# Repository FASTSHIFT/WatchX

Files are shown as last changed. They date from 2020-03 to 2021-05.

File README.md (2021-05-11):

# WatchX
> 开源智能手表, 高质量流畅(60FPS+)的动画效果, 易于扩展的系统框架.

演示视频：https://www.bilibili.com/video/BV1AK4y1b7Xd

## UI框架
> [LittlevGL V6.1.2](https://github.com/lvgl/lvgl/releases/tag/v6.1.2)

## 硬件配置
* 1.主控: STM32F411CEU6 (主频:100MHz RAM:128KB ROM:512KB)
* 2.屏幕: ST7789 IPS 1.14inch SPI接口 135x240分辨率 100Hz刷新率
* 3.输入设备: 按键x3
* 4.RTC:MCU内置RTC时钟
* 5.加速度计:MPU6050
* 6.气压计:BMP180
* 7.电源管理:TP4056 + TPS63070
## 功能
* 1.时间显示
* 2.温度显示
* 3.气压显示
* 4.海拔显示
* 5.秒表
* 6.亮度控制
* 7.时间设置
* 8.[Arduboy](https://github.com/Arduboy/Arduboy)/[Arduboy2](https://github.com/MLXXXp/Arduboy2) Game System
* 9.自动关机(5-300sec)
* 10.待续...

## 成品展示
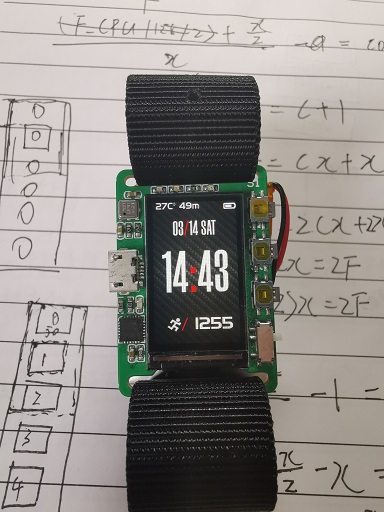
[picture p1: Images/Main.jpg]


 [更多>>](https://github.com/FASTSHIFT/WatchX/blob/master/Images)

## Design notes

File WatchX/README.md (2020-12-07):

# WatchX 更新日志
> https://github.com/FASTSHIFT/WatchX

## [v0.1] - 2020-03-07
* 1.框架搭建完成，UI基于littlevGL v6.1.2
* 2.优化屏幕驱动，刷新率提升至104FPS

## [v0.2] - 2020-03-11
* 1.主表盘界面完成
* 2.设置界面完成
* 3.时间设置界面完成

## [v0.3] - 2020-03-12
* 1.秒表完成
* 2.海拔表完成
* 3.About完成
* 4.所有功能基本完工

## [v0.4] - 2020-03-14
* 1.添加LV_OBJ_ADD_ANIM，更简洁的动画绑定

## [v0.5] - 2020-03-18
* 1.添加低功耗模式
* 2.添加Arduboy Game System
* 3.添加游戏 "CHRI-BOCCHI CAT"

## [v0.6] - 2020-03-23
* 1.海拔显示添加自动量程
* 2.添加MillisTaskManager，可统计CPU占用率
* 3.添加时间上下滑动特效

## [v0.7] - 2020-05-03
* 1.屏幕使用DMA发送，配合lvgl乒乓缓冲，画面无撕裂
* 2.Brightness更改为Backlight

## [v0.8] - 2020-06-27
* 1.修复电量显示的问题
* 2.添加 电源使能保持脚POWER_ON 和 电源使能按键状态读取脚POWER_EN
* 3.添加屏幕亮度掉电保存支持
* 4.添加自动待机时间设置以及掉电保存支持
* 5.感谢"日天电子工作室"提出的改进建议
* 6.修改了一些函数的命名

## [v0.9] - 2020-07-30
* 1.更新MillisTaskManager库，无需手动指定ID
* 2.TFT_LED_Pin 更名为 TFT_BLK_Pin
* 3.添加部分注释
* 4.Home更名为DialPlate(表盘)页面，Settings更名为MainMenu页面
* 5.更新PageManager v1.4
* 6.添加Arduboy2

## [v1.0] - 2020-12-07
* 1.POWER初始化整合
* 2.修改默认的动画曲线，更强的非线性效果，lv_anim_path_ease_in_out -> lv_anim_path_ease_out
* 3.修正错误的单词拼写，xxx_Creat -> xxx_Create， Fouce -> Focus
* 4.加大lv_disp_buf，使用两个半屏buffer，提升刷新率
* 5.去除FileGroup.h
* 6.更新海拔显示的tick自适应方法

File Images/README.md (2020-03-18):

# 成品展示
> 1.主页面



> 2.功能页面

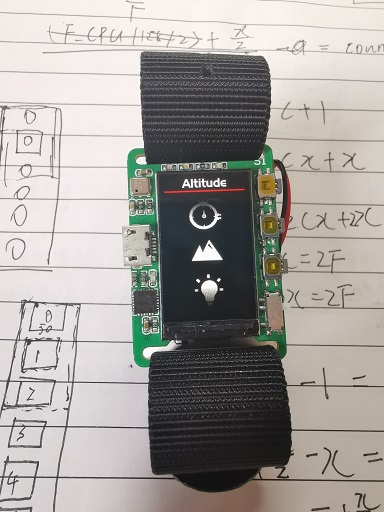
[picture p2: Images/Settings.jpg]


> 3.秒表

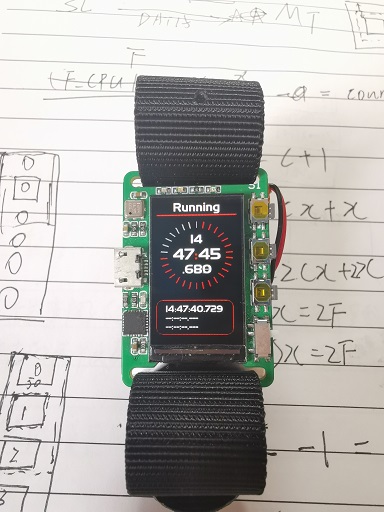
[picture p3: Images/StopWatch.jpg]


> 4.高度

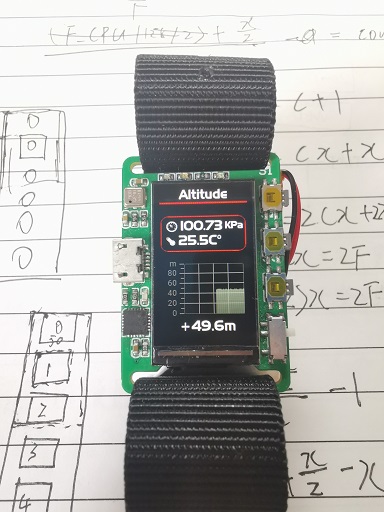
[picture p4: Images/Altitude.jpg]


> 5.亮度

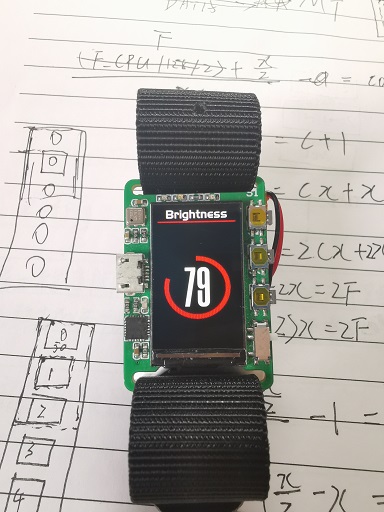
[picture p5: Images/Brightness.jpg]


> 6.时间设置

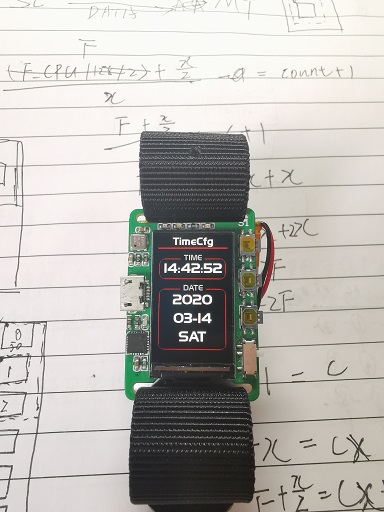
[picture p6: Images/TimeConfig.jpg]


> 7.关于

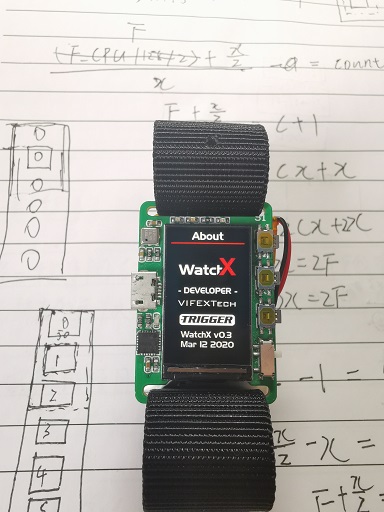
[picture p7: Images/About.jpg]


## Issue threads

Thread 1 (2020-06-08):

Compile error

yingjiexiong, 2020-06-08:
i had downloaded this project and  watching you video , it's so cool , but when I  ready to compile this project I find something error that located in audio.app 160 line, 164 line 170 line 175line .those error are same they are #19:extra text after expected end of number .

FASTSHIFT, 2020-06-10:
@yingjiexiong
I used Keil MDK-ARM v5.25 to compile, what compiler are you using?

yingjiexiong, 2020-06-15:
> @yingjiexiong
> I used Keil MDK-ARM v5.25 to compile, what compiler are you using?

thanks for your reply, I am using v5.14. I need to upgrade my compiler?

FASTSHIFT, 2020-06-15:
@yingjiexiong
Yes

tanhailong, 2020-09-04:
楼主我使用你这个代码编译不通过，我使用的MDK版本是V5.14,还是在编译这个工程的时候需要在mdk里面设置一下呢，期待你的回复

FASTSHIFT, 2020-09-04:
@tanhailong 请使用MDK-ARM v5.25以上的版本进行编译

heimareed, 2020-09-04:
> @tanhailong 请使用MDK-ARM v5.25以上的版本进行编译

楼主真快，还在回复，你就上去了~

tanhailong, 2020-09-04:
> @tanhailong 请使用MDK-ARM v5.25以上的版本进行编译

好的，我重新下载一下，使用V5.25以上版本就不会出现编译不通过的问题了吧？

tanhailong, 2020-09-04:
> > @tanhailong 请使用MDK-ARM v5.25以上的版本进行编译
>
> 楼主真快，还在回复，你就上去了~

我也觉得楼主回复很快，基本上是秒回

heimareed, 2020-09-04:
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

不要在这里回复了，成聊天室了。Watch了这个项目的都会收到邮件。另外，你提问的时候，建议附带异常描述说明，自己先去尝试解决。既然能上传上去，肯定编译之类的错误都是不会存在的。另外，先看之前的issue，包括已经关闭的。上面已经有人提问，楼主也回复了的。https://github.com/FASTSHIFT/WatchX/issues/1#issuecomment-641911792

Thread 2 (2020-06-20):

Info Please

DeonMarais64, 2020-06-20:
Hi,
This is a really cool project/product ! IMO it has a lot of scope and possibilities !

I am an embedded developer and amateur endurance athlete ( https://www.strava.com/athletes/12265248 ) and the prospect of being able to tinker with the wrist unit I use is very appealing to me even though it may not be sufficiently rugged for general use but for my purposes this is not a big problem.

Some questions,
1. Can I buy one or two units, If so where from and how ?
2. Do you have any plans to add Bluetooth and maybe WiFi to the hardware at some point ?
3. I have been using LVGL for a few years now and generally use the IAR compiler.
I am be willing to adapt the project to IAR for both IAR and Eclipse IDE's and in future VisualGDB ( https://visualgdb.com/ ) using either IAR and/Or GNU Compilers. I am also willing to migrate the source code for LVGL V7.x compatibility. Would you welcome collaboration in this regard ?

Looking forward to your response.

FASTSHIFT, 2020-06-21:
@DeonMarais64
1. International express delivery may be inconvenient, you can refer to the PCB in the "Hardware" folder for production.
2. I will consider adding Bluetooth and WiFi. ESP32 is a good choice.
3. It should be easy to port this program to IAR for compilation. I will try it later.

Closed 2022-11-09.

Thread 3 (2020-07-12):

不能正常下载

juruoWYC, 2020-07-12:
您好！非常棒的软硬件设计，感谢分享！
我用原版PCB打样并且焊好了三块，现在遇到问题：ST-LINK Utility和MDK都只能识别到单片机，不能下载，焊接检查了没有问题，用按住Reset再松开的办法也不能正常下载，请问你有这个问题吗？如何debug呢？谢谢

FASTSHIFT, 2020-07-12:
@juruoWYC
可能是没有在keil内添加 STM32F4xx_512.FLM 烧写算法文件，这个文件位于Core/CMSIS/Flash文件夹内

juruoWYC, 2020-07-13:
感谢回复。
这个文件是添加并且选择了的，报错 erase failed

FASTSHIFT, 2020-07-13:
@juruoWYC
加我Q吧，可能是哪里设置不对

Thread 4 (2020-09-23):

应用于单片机需要增加ArduinoAPI吗

sanluku, 2020-09-23:
如果应用于单片机需要增加ArduinoAPI吗？我看里面的编译又会include stm32的库进来。
我正要运行到nrf52832上面

FASTSHIFT, 2020-09-23:
@sanluku
ArduinoAPI与Core的内容是和stm32耦合的。
如果想移植到nrf52832平台，就要先将WatchX应用层与stm32底层解耦，再和nrf52832 SDK对接。

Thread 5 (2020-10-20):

关于嘉立创SMT贴片的问题

XZXAAA, 2020-10-20:
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
如果想要再嘉立创打SMT贴片的话，PCB文件中使用元器件封装是否跟嘉立创的封装标准对应

FASTSHIFT, 2020-10-20:
@XZXAAA 暂未尝试过嘉立创SMT

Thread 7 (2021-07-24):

您好，能否问下如何移植到STM32F429或F407上去呢？

marseric, 2021-07-24:
非常棒的项目！
手头正好有一块F429和F407的开发板，还有一块7寸的触摸屏。
请问您这个如何移植呢？
非常感谢

FASTSHIFT, 2021-07-24:
可以尝试切换工程的芯片选型，重新编译，不用修改引脚。

marseric, 2021-07-25:
好的，正在仔细学习您的代码。方便的话，能大概说下您的具体的开发流程和使用的GUI工具吗？认真学习下大佬的精髓:)

FASTSHIFT, 2021-07-25:
Keil v5.25和Adobe AI，UI是手写的

marseric, 2021-07-25:
您好，感觉这个项目组织的非常精妙！请问手表程序长期运行的稳定性如何？
另外， PageManager 和 MillisTaskManager 两个库都很棒，请问在哪里能找到更多的相关资料呢？谢谢！

FASTSHIFT, 2021-07-25:
长期运行没有测试过。
PageManager 和 MillisTaskManager 是我原创的，可以参考程序和代码注释来理解。
我建议您可以了解一下[X-TRACK](https://github.com/FASTSHIFT/X-TRACK)采用的新架构。

marseric, 2021-07-25:
好的，谢谢您写了这么棒的代码并分享给世界:)

marseric, 2021-07-27:
您好，尝试了切换工程的芯片（正点原子F407ZGT6开发板），编译没有错误。
但是下载后程序好像没有反应（尝试点亮LED灯，没有成功）。。。是不是工程里面的Startup文件夹也需要选择重新选择呢？多谢您的指点:)
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

FASTSHIFT, 2021-07-27:
@marseric
需要手动修改启动文件，默认的是F411。

marseric, 2021-07-27:
您好，已经切换了启动文件到F40_41xxx.s，编译没问题。
但是下载后，LED灯还是没法工作（用的正点原子跑马灯LED例程，库函数版本）。您看还有可能是其它的问题吗？谢谢您的指点

FASTSHIFT, 2021-07-27:
@marseric
进DEBUG，看看main函数进入没。
如果代码中使用了`printf()`，请删除，使用`Serial.printf()`替换。

marseric, 2021-07-27:
多谢回复，按照您的方法，进入DEBUG，报 error 65
 error 65: access violation at 0x40023800 : no 'read' permission
在SystemInit函数内

marseric, 2021-07-27:
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

FASTSHIFT, 2021-07-27:
@marseric
运行WatchX需要在启动文件中修改堆栈大小的。
加我微信吧，微信号：FASTSHIFT

marseric, 2021-07-27:
好的，谢谢您:)

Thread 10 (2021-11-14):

PageManager移植问题请教

marseric, 2021-11-14:
您好，冒昧的打搅一下： 因为很喜欢watchX里面的pagemanager库。所以尝试把您的库集成到了之前自己的keil工程里面（stm32F429），并加上了--gnu选项。现在编译器报很多错误。您看可能是哪里的问题呢？感谢！
Build started: Project: NETWORK
*** Using Compiler 'V5.06 update 6 (build 750)', folder: 'D:\PROGRAM\Keil\ARM\ARMCC\Bin'
Build target 'NETWORK'
compiling main.c...
..\LWIP\lwip-1.4.1\src\include\ipv4\lwip/ip_addr.h(53): warning:  #3135-D: attribute does not apply to any entity
  PACK_STRUCT_BEGIN
..\LWIP\lwip-1.4.1\src\include\ipv4\lwip/ip_addr.h(74): warning:  #3135-D: attribute does not apply to any entity
  PACK_STRUCT_BEGIN
..\GUI\DisplayPrivate.h(19): warning:  #1295-D: Deprecated declaration DisplayError_Init - give arg types
  void DisplayError_Init();
..\GUI\DisplayPrivate.h(20): warning:  #1295-D: Deprecated declaration Display_Init - give arg types
  void Display_Init();
..\GUI\DisplayPrivate.h(21): warning:  #1295-D: Deprecated declaration Display_Update - give arg types
  void Display_Update();
..\Libraries\PageManager\PageManager.h(44): error:  #20: identifier "class" is undefined
  class PageManager {
..\Libraries\PageManager\PageManager.h(44): error:  #65: expected a ";"
  class PageManager {
..\Libraries\PageManager\PageManager.h(65): warning:  #12-D: parsing restarts here after previous syntax error
      );
..\Libraries\PageManager\PageManager.h(68): warning:  #1295-D: Deprecated declaration PagePop - give arg types
      bool PagePop();
..\Libraries\PageManager\PageManager.h(71): warning:  #1295-D: Deprecated declaration PageStackClear - give arg types
      void PageStackClear();
..\Libraries\PageManager\PageManager.h(72): warning:  #1295-D: Deprecated declaration Running - give arg types
      void Running();
..\Libraries\PageManager\PageManager.h(73): warning:  #77-D: this declaration has no storage class or type specifier
  private:
..\Libraries\PageManager\PageManager.h(73): error:  #65: expected a ";"
  private:
..\Libraries\PageManager\PageManager.h(80): error:  #169: expected a declaration
  };
..\GUI\DisplayPrivate.h(42): error:  #757: variable "PageManager"  is not a type name
  extern PageManager page;
..\GUI\DisplayPrivate.h(55): warning:  #1295-D: Deprecated declaration lv_port_disp_init - give arg types
  void lv_port_disp_init();
..\GUI\DisplayPrivate.h(67): error:  #18: expected a ")"
      uint16_t time = LV_ANIM_TIME_DEFAULT,
..\GUI\DisplayPrivate.h(70): warning:  #12-D: parsing restarts here after previous syntax error
  );
..\GUI\DisplayPrivate.h(84): warning:  #1295-D: Deprecated declaration AppWindow_Create - give arg types
  void AppWindow_Create();
..\GUI\DisplayPrivate.h(86): warning:  #1295-D: Deprecated declaration AppWindow_GetHeight - give arg types
  lv_coord_t AppWindow_GetHeight();
..\GUI\DisplayPrivate.h(87): warning:  #1295-D: Deprecated declaration AppWindow_GetWidth - give arg types
  lv_coord_t AppWindow_GetWidth();
main.c(212): warning:  #223-D: function "W25QXX_Init" declared implicitly
      W25QXX_Init();				//SPI W25Q128 init 32MByte
main.c(283): warning:  #223-D: function "app_system_parameter_init" declared implicitly
   	if(app_system_parameter_init())
main.c(193): warning:  #177-D: variable "res"  was declared but never referenced
  	u8 res;
main.c(194): warning:  #177-D: variable "dtsize"  was declared but never referenced
  	u32 dtsize,dfsize;
main.c(194): warning:  #177-D: variable "dfsize"  was declared but never referenced
  	u32 dtsize,dfsize;
main.c(195): warning:  #177-D: variable "stastr"  was declared but never referenced
  	u8 *stastr=0;
main.c(196): warning:  #177-D: variable "version"  was declared but never referenced
  	u8 *version=0;
main.c(197): warning:  #177-D: variable "verbuf"  was declared but never referenced
  	u8 verbuf[12];
main.c(199): warning:  #177-D: variable "icowidth"  was declared but never referenced
  	u8 icowidth;
main.c(681): warning:  #1035-D: single-precision operand implicitly converted to double-precision
  		ad[0].Temp = p1*ad[0].Rt*ad[0].Rt*ad[0].Rt*ad[0].Rt + p2*ad[0].Rt*ad[0].Rt*ad[0].Rt + p3*ad[0].Rt*ad[0].Rt + p4*ad[0].Rt + p5;
main.c(681): warning:  #1035-D: single-precision operand implicitly converted to double-precision
  		ad[0].Temp = p1*ad[0].Rt*ad[0].Rt*ad[0].Rt*ad[0].Rt + p2*ad[0].Rt*ad[0].Rt*ad[0].Rt + p3*ad[0].Rt*ad[0].Rt + p4*ad[0].Rt + p5;
main.c(681): warning:  #1035-D: single-precision operand implicitly converted to double-precision
  		ad[0].Temp = p1*ad[0].Rt*ad[0].Rt*ad[0].Rt*ad[0].Rt + p2*ad[0].Rt*ad[0].Rt*ad[0].Rt + p3*ad[0].Rt*ad[0].Rt + p4*ad[0].Rt + p5;
main.c(725): warning:  #1035-D: single-precision operand implicitly converted to double-precision
  		ad[1].Temp = p1*ad[1].Rt*ad[1].Rt*ad[1].Rt*ad[1].Rt + p2*ad[1].Rt*ad[1].Rt*ad[1].Rt + p3*ad[1].Rt*ad[1].Rt + p4*ad[1].Rt + p5;
main.c(725): warning:  #1035-D: single-precision operand implicitly converted to double-precision
  		ad[1].Temp = p1*ad[1].Rt*ad[1].Rt*ad[1].Rt*ad[1].Rt + p2*ad[1].Rt*ad[1].Rt*ad[1].Rt + p3*ad[1].Rt*ad[1].Rt + p4*ad[1].Rt + p5;
main.c(725): warning:  #1035-D: single-precision operand implicitly converted to double-precision
  		ad[1].Temp = p1*ad[1].Rt*ad[1].Rt*ad[1].Rt*ad[1].Rt + p2*ad[1].Rt*ad[1].Rt*ad[1].Rt + p3*ad[1].Rt*ad[1].Rt + p4*ad[1].Rt + p5;
main.c(769): warning:  #1035-D: single-precision operand implicitly converted to double-precision
  		ad[2].Temp = p1*ad[2].Rt*ad[2].Rt*ad[2].Rt*ad[2].Rt + p2*ad[2].Rt*ad[2].Rt*ad[2].Rt + p3*ad[2].Rt*ad[2].Rt + p4*ad[2].Rt + p5;
main.c(769): warning:  #1035-D: single-precision operand implicitly converted to double-precision
  		ad[2].Temp = p1*ad[2].Rt*ad[2].Rt*ad[2].Rt*ad[2].Rt + p2*ad[2].Rt*ad[2].Rt*ad[2].Rt + p3*ad[2].Rt*ad[2].Rt + p4*ad[2].Rt + p5;
main.c(769): warning:  #1035-D: single-precision operand implicitly converted to double-precision
  		ad[2].Temp = p1*ad[2].Rt*ad[2].Rt*ad[2].Rt*ad[2].Rt + p2*ad[2].Rt*ad[2].Rt*ad[2].Rt + p3*ad[2].Rt*ad[2].Rt + p4*ad[2].Rt + p5;
main.c(812): warning:  #1035-D: single-precision operand implicitly converted to double-precision
  		ad[3].Temp = p1*ad[3].Rt*ad[3].Rt*ad[3].Rt*ad[3].Rt + p2*ad[3].Rt*ad[3].Rt*ad[3].Rt + p3*ad[3].Rt*ad[3].Rt + p4*ad[3].Rt + p5;
main.c(812): warning:  #1035-D: single-precision operand implicitly converted to double-precision
  		ad[3].Temp = p1*ad[3].Rt*ad[3].Rt*ad[3].Rt*ad[3].Rt + p2*ad[3].Rt*ad[3].Rt*ad[3].Rt + p3*ad[3].Rt*ad[3].Rt + p4*ad[3].Rt + p5;
main.c(812): warning:  #1035-D: single-precision operand implicitly converted to double-precision
  		ad[3].Temp = p1*ad[3].Rt*ad[3].Rt*ad[3].Rt*ad[3].Rt + p2*ad[3].Rt*ad[3].Rt*ad[3].Rt + p3*ad[3].Rt*ad[3].Rt + p4*ad[3].Rt + p5;
main.c(820): warning:  #1035-D: single-precision operand implicitly converted to double-precision
  		ad7705ctr1 += 0.5;
main.c: 37 warnings, 6 errors
"..\OBJ\Tempate.axf" - 6 Error(s), 37 Warning(s).
Target not created.
Build Time Elapsed:  00:00:10

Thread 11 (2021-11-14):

PageManager移植问题

marseric, 2021-11-14:
您好，冒昧的打搅一下： 因为很喜欢watchX里面的pagemanager库。所以尝试把您的库集成到了之前自己的keil工程里面（stm32F429），并加上了--gnu选项。现在编译器报很多错误。您看可能是哪里的问题呢？感谢！
Build started: Project: NETWORK
*** Using Compiler 'V5.06 update 6 (build 750)', folder: 'D:\PROGRAM\Keil\ARM\ARMCC\Bin'
Build target 'NETWORK'
compiling main.c...
..\LWIP\lwip-1.4.1\src\include\ipv4\lwip/ip_addr.h(53): warning:  #3135-D: attribute does not apply to any entity
  PACK_STRUCT_BEGIN
..\LWIP\lwip-1.4.1\src\include\ipv4\lwip/ip_addr.h(74): warning:  #3135-D: attribute does not apply to any entity
  PACK_STRUCT_BEGIN
..\GUI\DisplayPrivate.h(19): warning:  #1295-D: Deprecated declaration DisplayError_Init - give arg types
  void DisplayError_Init();
..\GUI\DisplayPrivate.h(20): warning:  #1295-D: Deprecated declaration Display_Init - give arg types
  void Display_Init();
..\GUI\DisplayPrivate.h(21): warning:  #1295-D: Deprecated declaration Display_Update - give arg types
  void Display_Update();
..\Libraries\PageManager\PageManager.h(44): error:  #20: identifier "class" is undefined
  class PageManager {
..\Libraries\PageManager\PageManager.h(44): error:  #65: expected a ";"
  class PageManager {
..\Libraries\PageManager\PageManager.h(65): warning:  #12-D: parsing restarts here after previous syntax error
      );
..\Libraries\PageManager\PageManager.h(68): warning:  #1295-D: Deprecated declaration PagePop - give arg types
      bool PagePop();
..\Libraries\PageManager\PageManager.h(71): warning:  #1295-D: Deprecated declaration PageStackClear - give arg types
      void PageStackClear();
..\Libraries\PageManager\PageManager.h(72): warning:  #1295-D: Deprecated declaration Running - give arg types
      void Running();
..\Libraries\PageManager\PageManager.h(73): warning:  #77-D: this declaration has no storage class or type specifier
  private:
..\Libraries\PageManager\PageManager.h(73): error:  #65: expected a ";"
  private:
..\Libraries\PageManager\PageManager.h(80): error:  #169: expected a declaration
  };
..\GUI\DisplayPrivate.h(42): error:  #757: variable "PageManager"  is not a type name
  extern PageManager page;
..\GUI\DisplayPrivate.h(55): warning:  #1295-D: Deprecated declaration lv_port_disp_init - give arg types
  void lv_port_disp_init();
..\GUI\DisplayPrivate.h(67): error:  #18: expected a ")"
      uint16_t time = LV_ANIM_TIME_DEFAULT,
..\GUI\DisplayPrivate.h(70): warning:  #12-D: parsing restarts here after previous syntax error
  );
..\GUI\DisplayPrivate.h(84): warning:  #1295-D: Deprecated declaration AppWindow_Create - give arg types
  void AppWindow_Create();
..\GUI\DisplayPrivate.h(86): warning:  #1295-D: Deprecated declaration AppWindow_GetHeight - give arg types
  lv_coord_t AppWindow_GetHeight();
..\GUI\DisplayPrivate.h(87): warning:  #1295-D: Deprecated declaration AppWindow_GetWidth - give arg types
  lv_coord_t AppWindow_GetWidth();
main.c(212): warning:  #223-D: function "W25QXX_Init" declared implicitly
      W25QXX_Init();				//SPI W25Q128 init 32MByte
main.c(283): warning:  #223-D: function "app_system_parameter_init" declared implicitly
   	if(app_system_parameter_init())
main.c(193): warning:  #177-D: variable "res"  was declared but never referenced
  	u8 res;
main.c(194): warning:  #177-D: variable "dtsize"  was declared but never referenced
  	u32 dtsize,dfsize;
main.c(194): warning:  #177-D: variable "dfsize"  was declared but never referenced
  	u32 dtsize,dfsize;
main.c(195): warning:  #177-D: variable "stastr"  was declared but never referenced
  	u8 *stastr=0;
main.c(196): warning:  #177-D: variable "version"  was declared but never referenced
  	u8 *version=0;
main.c(197): warning:  #177-D: variable "verbuf"  was declared but never referenced
  	u8 verbuf[12];
main.c(199): warning:  #177-D: variable "icowidth"  was declared but never referenced
  	u8 icowidth;
main.c(681): warning:  #1035-D: single-precision operand implicitly converted to double-precision
  		ad[0].Temp = p1*ad[0].Rt*ad[0].Rt*ad[0].Rt*ad[0].Rt + p2*ad[0].Rt*ad[0].Rt*ad[0].Rt + p3*ad[0].Rt*ad[0].Rt + p4*ad[0].Rt + p5;
main.c(681): warning:  #1035-D: single-precision operand implicitly converted to double-precision
  		ad[0].Temp = p1*ad[0].Rt*ad[0].Rt*ad[0].Rt*ad[0].Rt + p2*ad[0].Rt*ad[0].Rt*ad[0].Rt + p3*ad[0].Rt*ad[0].Rt + p4*ad[0].Rt + p5;
main.c(681): warning:  #1035-D: single-precision operand implicitly converted to double-precision
  		ad[0].Temp = p1*ad[0].Rt*ad[0].Rt*ad[0].Rt*ad[0].Rt + p2*ad[0].Rt*ad[0].Rt*ad[0].Rt + p3*ad[0].Rt*ad[0].Rt + p4*ad[0].Rt + p5;
main.c(725): warning:  #1035-D: single-precision operand implicitly converted to double-precision
  		ad[1].Temp = p1*ad[1].Rt*ad[1].Rt*ad[1].Rt*ad[1].Rt + p2*ad[1].Rt*ad[1].Rt*ad[1].Rt + p3*ad[1].Rt*ad[1].Rt + p4*ad[1].Rt + p5;
main.c(725): warning:  #1035-D: single-precision operand implicitly converted to double-precision
  		ad[1].Temp = p1*ad[1].Rt*ad[1].Rt*ad[1].Rt*ad[1].Rt + p2*ad[1].Rt*ad[1].Rt*ad[1].Rt + p3*ad[1].Rt*ad[1].Rt + p4*ad[1].Rt + p5;
main.c(725): warning:  #1035-D: single-precision operand implicitly converted to double-precision
  		ad[1].Temp = p1*ad[1].Rt*ad[1].Rt*ad[1].Rt*ad[1].Rt + p2*ad[1].Rt*ad[1].Rt*ad[1].Rt + p3*ad[1].Rt*ad[1].Rt + p4*ad[1].Rt + p5;
main.c(769): warning:  #1035-D: single-precision operand implicitly converted to double-precision
  		ad[2].Temp = p1*ad[2].Rt*ad[2].Rt*ad[2].Rt*ad[2].Rt + p2*ad[2].Rt*ad[2].Rt*ad[2].Rt + p3*ad[2].Rt*ad[2].Rt + p4*ad[2].Rt + p5;
main.c(769): warning:  #1035-D: single-precision operand implicitly converted to double-precision
  		ad[2].Temp = p1*ad[2].Rt*ad[2].Rt*ad[2].Rt*ad[2].Rt + p2*ad[2].Rt*ad[2].Rt*ad[2].Rt + p3*ad[2].Rt*ad[2].Rt + p4*ad[2].Rt + p5;
main.c(769): warning:  #1035-D: single-precision operand implicitly converted to double-precision
  		ad[2].Temp = p1*ad[2].Rt*ad[2].Rt*ad[2].Rt*ad[2].Rt + p2*ad[2].Rt*ad[2].Rt*ad[2].Rt + p3*ad[2].Rt*ad[2].Rt + p4*ad[2].Rt + p5;
main.c(812): warning:  #1035-D: single-precision operand implicitly converted to double-precision
  		ad[3].Temp = p1*ad[3].Rt*ad[3].Rt*ad[3].Rt*ad[3].Rt + p2*ad[3].Rt*ad[3].Rt*ad[3].Rt + p3*ad[3].Rt*ad[3].Rt + p4*ad[3].Rt + p5;
main.c(812): warning:  #1035-D: single-precision operand implicitly converted to double-precision
  		ad[3].Temp = p1*ad[3].Rt*ad[3].Rt*ad[3].Rt*ad[3].Rt + p2*ad[3].Rt*ad[3].Rt*ad[3].Rt + p3*ad[3].Rt*ad[3].Rt + p4*ad[3].Rt + p5;
main.c(812): warning:  #1035-D: single-precision operand implicitly converted to double-precision
  		ad[3].Temp = p1*ad[3].Rt*ad[3].Rt*ad[3].Rt*ad[3].Rt + p2*ad[3].Rt*ad[3].Rt*ad[3].Rt + p3*ad[3].Rt*ad[3].Rt + p4*ad[3].Rt + p5;
main.c(820): warning:  #1035-D: single-precision operand implicitly converted to double-precision
  		ad7705ctr1 += 0.5;
main.c: 37 warnings, 6 errors
"..\OBJ\Tempate.axf" - 6 Error(s), 37 Warning(s).
Target not created.
Build Time Elapsed:  00:00:10

FASTSHIFT, 2022-06-24:
C不能直接用C++库，语法不兼容。可以把调用库的C文件改成CPP文件，或者重写PageManger使用结构体模拟class。

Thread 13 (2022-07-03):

lvgl只能显示一半的图片

Thawnoy, 2022-07-03:
移植了楼主的lvgl显示驱动，在1.14寸屏幕上只能显示一般的图案

FASTSHIFT, 2022-07-03:
DMA单次传输的数据量有限，如果单次传输数据量大于65535，需要拆包处理，参考 https://github.com/FASTSHIFT/X-TRACK/blob/main/Software/X-Track/MDK-ARM_F403A/Platform/HAL/HAL_Display.cpp

Thawnoy, 2022-07-03:
首先感谢指教。但是十分抱歉，文本打错字了，我的issue是屏幕上只显示一半图片。十分感谢

| |
***@***.***
|
|
***@***.***
|

---- 回复的原邮件 ----
| 发件人 | ***@***.***> |
| 日期 | 2022年07月03日 21:37 |
| 收件人 | ***@***.***> |
| 抄送至 | ***@***.******@***.***> |
| 主题 | Re: [FASTSHIFT/WatchX] lvgl只能显示一半的图片 (Issue #13) |

DMA单次传输的数据量有限，如果单次传输数据量大于65535，需要拆包处理，参考 https://github.com/FASTSHIFT/X-TRACK/blob/main/Software/X-Track/MDK-ARM_F403A/Platform/HAL/HAL_Display.cpp

—
Reply to this email directly, view it on GitHub, or unsubscribe.
You are receiving this because you authored the thread.Message ID: ***@***.***>

FASTSHIFT, 2022-07-03:
发图和代码

Thawnoy, 2022-07-03:
图片和代码发到了github提供的邮箱中，如果方便请提供一下联系方式，有许多这个项目问题希望得到解答

在 2022-07-03 22:18:12，"_VIFEXTech" ***@***.***> 写道：

发图和代码

—
Reply to this email directly, view it on GitHub, or unsubscribe.
You are receiving this because you authored the thread.Message ID: ***@***.***>

FASTSHIFT, 2022-07-03:
> 图片和代码发到了github提供的邮箱中，如果方便请提供一下联系方式，有许多这个项目问题希望得到解答 在 2022-07-03 22:18:12，"_VIFEXTech" ***@***.***> 写道： 发图和代码 — Reply to this email directly, view it on GitHub, or unsubscribe. You are receiving this because you authored the thread.Message ID: ***@***.***>

issue也能贴图片。
先确保屏幕驱动没有问题再上LVGL，这个现象看着像分辨率设置或者屏幕方向设置的问题。

FASTSHIFT, 2022-07-05:
@Thawnoy
注册的任务必须是非阻塞的

Thawnoy, 2022-07-06:
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
您好，您知道这个现象是为什么吗

FASTSHIFT, 2022-07-06:
> 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 您好，您知道这个现象是为什么吗

lv_demo_widgets/benchmark可以正常跑吗？先排除驱动问题。再检查应用层是不是哪里内存越界导致的运行异常，建议UI开发工作转移到PC模拟器上进行开发，有[ASAN](https://docs.microsoft.com/zh-cn/cpp/sanitizers/asan?view=msvc-170)进行辅助很容易发现问题。

FASTSHIFT, 2022-07-06:
> 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 您好，您知道这个现象是为什么吗

lv_demo_widgets/benchmark可以正常跑吗？先排除驱动问题。再检查应用层是不是哪里内存越界导致的运行异常，建议UI开发工作转移到PC模拟器上进行开发，有[ASAN](https://docs.microsoft.com/zh-cn/cpp/sanitizers/asan?view=msvc-170)进行辅助很容易发现问题。

Thawnoy, 2022-07-06:
你好，感谢回复，但是lvgl6.1.1的benchmark例程是要触屏的，其他的tutorial例程运行正常

Thawnoy, 2022-07-06:
你好，benchmark的例程需要触摸驱动，但是试了一下animation的例程有的时候颜色会乱掉了。另外运行这套UI的时候会死机

Closed 2022-07-11.

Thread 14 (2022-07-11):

死机问题

Thawnoy, 2022-07-11:
从主页面进入到菜单正常，但是从菜单进入其他页面会卡死在Setup

FASTSHIFT, 2022-07-11:
改代码或工程配置了？具体停在哪一行？

Thawnoy, 2022-07-12:
你好，感谢回复，自己写的UI，并不是堆栈大小的问题，而是因为某些页面的特定控件的语句导致的死机，单调就正常了，这是什么原因呢

Thawnoy, 2022-07-12:
你好，感谢回复，自己写的UI，并不是堆栈大小的问题，而是因为某些页面的特定控件的语句导致的死机，删掉就正常了，这是什么原因呢

FASTSHIFT, 2022-07-12:
一般上就是内存访问越界或者空指针什么的，可以用[cmbacktrace](https://github.com/armink/CmBacktrace)分析一下。还是建议把UI开发调试工作转移到PC模拟器，配合ASAN等工具抓内存问题。

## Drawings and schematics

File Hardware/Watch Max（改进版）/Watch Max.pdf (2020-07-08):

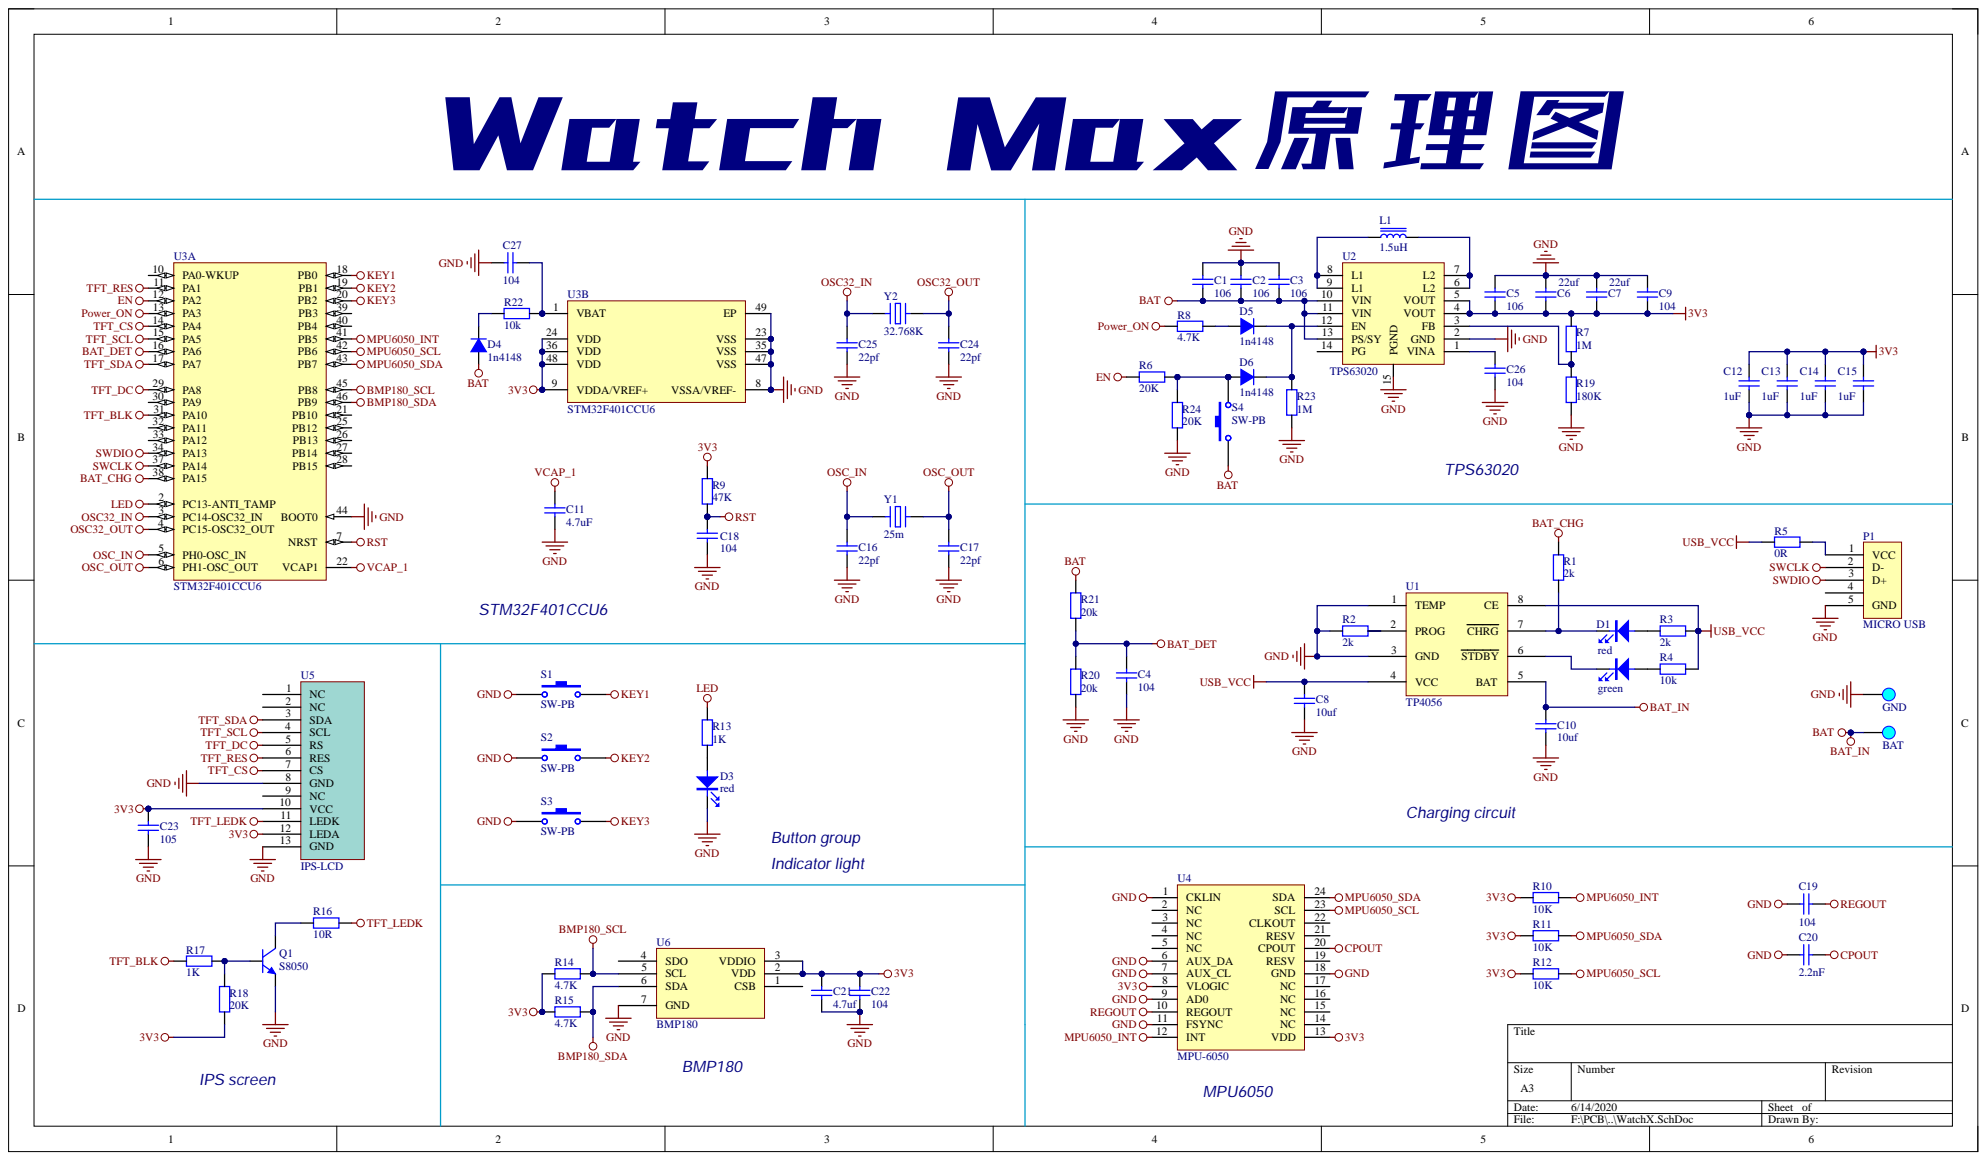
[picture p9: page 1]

U5 | S1 KEY1 Button group Indicator light

Size A3 | Number | Revision

Date: 6/14/2020 | Sheet of
File: F:\PCB\..\WatchX.SchDoc | Drawn By:

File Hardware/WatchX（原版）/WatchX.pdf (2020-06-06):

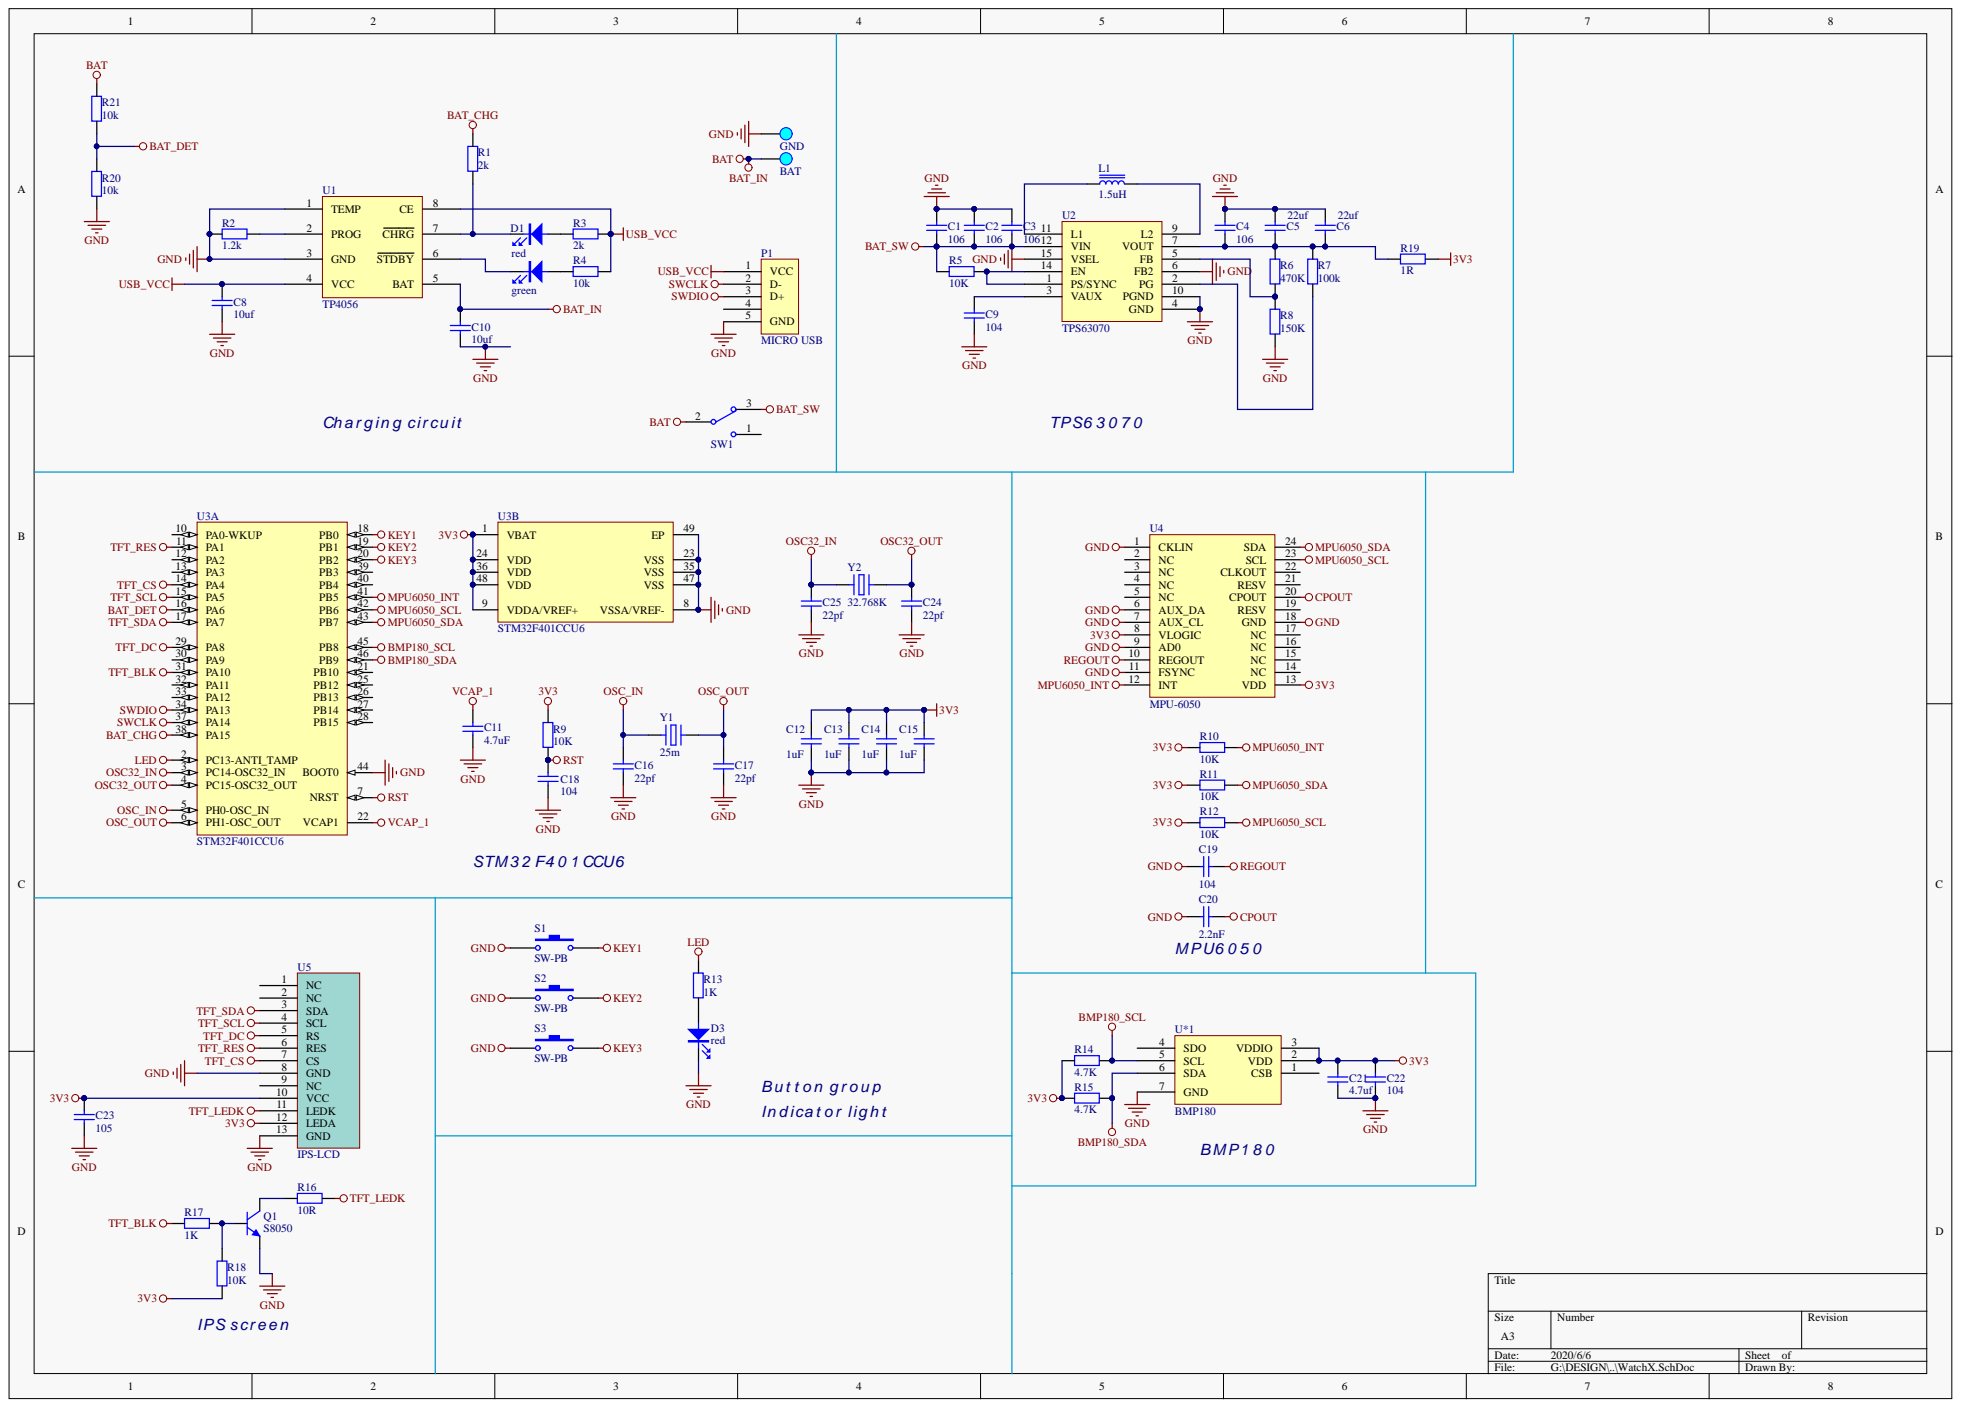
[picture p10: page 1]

Ch a r g in g cir cu it

NC 1 | S2 | In d i ca t o r l ig h t | BMP180_SCL U*1
NC 2 | SW-PB S3

LEDK 11 | | GND

GND 13 | | BMP180_SDA

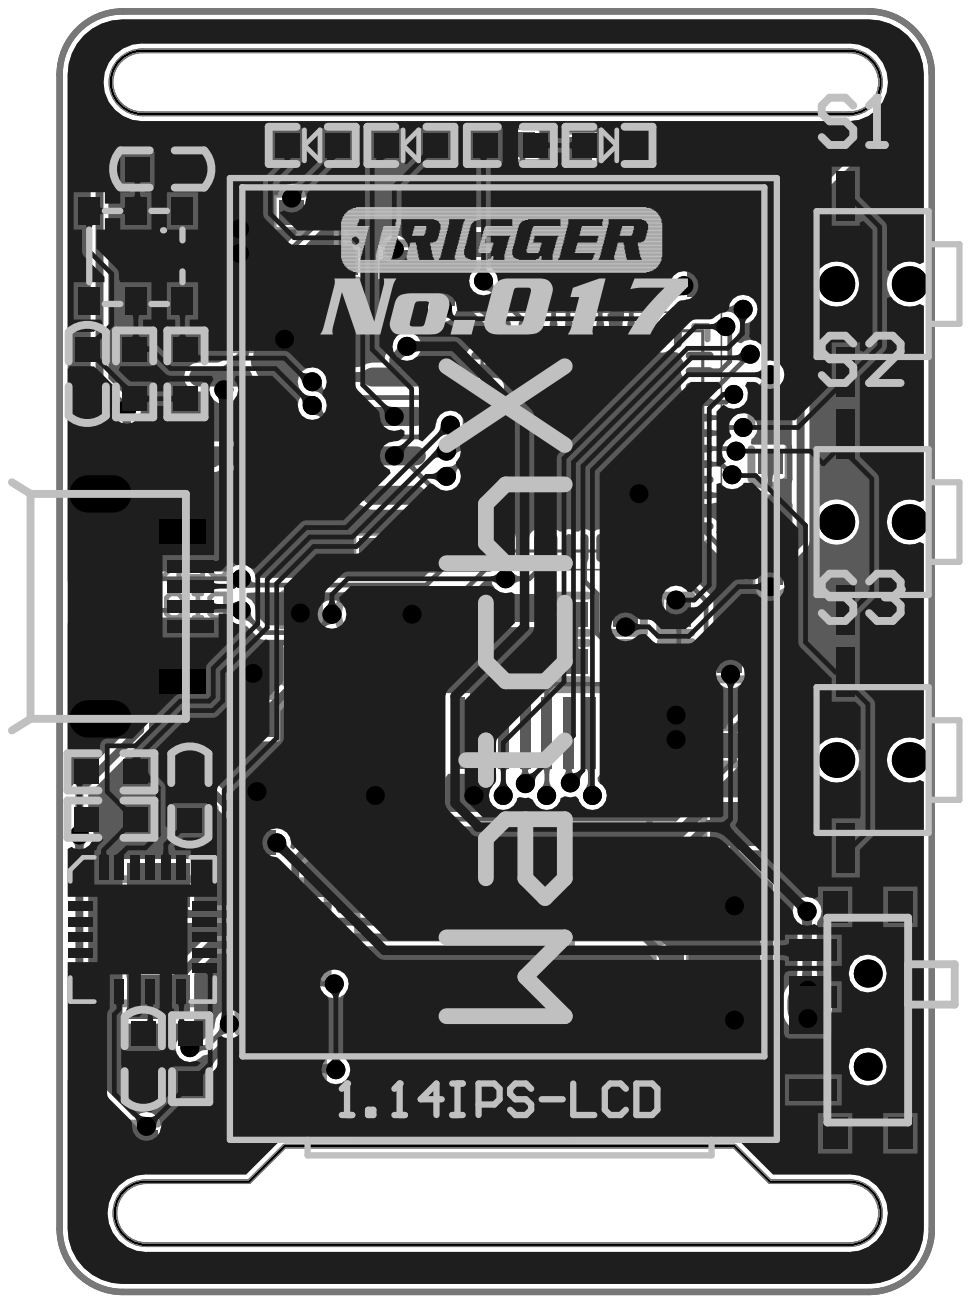
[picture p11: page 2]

Comment | Description | Designator | Footprint | LibRef | Quantity
106 | | C1, C2 | 电容_C0805 | cap | 2
106 | | C3, C4 | 电容_C0603 | cap | 2
22uf | | C5, C6 | 电容_C1206 | cap | 2
10uf | | C8, C10 | 电容_C0603 | cap | 2
104 | | C9, C18, C19, C22 | 电容_C0603 | cap | 4
4.7uF | | C11, C21 | 电容_C0603 | cap | 2
1uF | | C12, C13, C14, C15 | 电容_C0603 | cap | 4
22pf | | C16, C17, C24, C25 | 电容_C0603 | cap | 4
2.2nF | | C20 | 电容_C0603 | cap | 1
105 | | C23 | 电容_C0603 | cap | 1
red | | D1, D3 | LED_0603 | LED | 2
green | | D2 | LED_0603 | LED | 1
1.5uH | | L1 | 变压器电感_0420 | Inductor Iron 2 | 1
MICRO USB | | P1 | 接插件_MICRO 牛角 插座 USB 卷边 | MICRO USB 5PIN | 1
GND | | Pad1 | Pad_A | Pad | 1
BAT | | Pad2 | Pad_A | Pad | 1
S8050 | | Q1 | 三极管_SOT-23 | Triode-NPN | 1
2k | | R1, R3, R4 | 电阻_R0603 | Res | 3
1.2k | | R2 | 电阻_R0603 | Res | 1
10K | | R5, R9, R10, R11, R12, R18, R20, R21 | 电阻_R0603 | Res | 8
470K | | R6 | 电阻_R0603 | Res | 1
100k | | R7 | 电阻_R0603 | Res | 1
150K | | R8 | 电阻_R0603 | Res | 1
1K | | R13, R17 | 电阻_R0603 | Res | 2
4.7K | | R14, R15 | 电阻_R0603 | Res | 2
10R | | R16 | 电阻_R0603 | Res | 1
1R | | R19 | 电阻_R0603 | Res | 1
SW-PB | 按键 | S1, S2, S3 | KEY_3.5*4.7 | SW-PB | 3
SPDT | 开关-两档 | SW1 | MSS3-Q-T/R | SW_SPDT | 1
TP4056 | | U1 | SOP8 | TP4056 | 1
TPS63070 | 降压-升压转换器 | U2 | VQFN-15-HR | TPS63070 | 1
STM32F401CCU6 | ARM Cortex-M4 32-bit MCU+FPU, 105 DMIPS, 256 kB Flash, 64 kB Internal RAM, 36 I/Os, 48-pin UFQFPN, -40 to 85 degC, Tray | U3 | STM-UFQFPN48_N | STM32F401CCU6 | 1
MPU-6050 | | U4 | 陀螺仪_QFN24 | MPU-6050 | 1
IPS-LCD | IPS-LCD-1.14寸裸屏 spi接口 | U5 | 1.14IPS-LCD | IPS-LCD-1.14 | 1
BMP180 | 数字气压传感器 | U*1 | LGA-7 | BMP180 | 1
XTAL | | Y1 | 晶振_2016 | XTAL | 1
32.768K | | Y2 | 晶振_3215 | XTAL_A | 1

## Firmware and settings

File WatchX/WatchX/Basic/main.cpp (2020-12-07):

#include "BSP/BSP.h"
#include "GUI/DisplayPrivate.h"
#include "MillisTaskManager/MillisTaskManager.h"

/*任务调度器*/
static MillisTaskManager mtmMain;

/*CPU占用率(DEBUG用)*/
float CPU_Usage;

/**
  * @brief  CPU占用率更新
  * @param  无
  * @retval 无
  */
static void CPU_UsageUpdate()
{
    CPU_Usage = mtmMain.GetCPU_Usage();
}

/**
  * @brief  系统初始化
  * @param  无
  * @retval 无
  */
static void setup()
{
    LED_Init();
    LED_SetEnable(true);

    /*设备初始化*/
    Power_Init();
    RTCx_Init();
    Backlight_Init();
    Button_Init();
    Display_Init();
    BMP_Init();
    ADC_DMA_Init();

    LED_SetEnable(false);

    /*任务注册*/
    mtmMain.Register(Display_Update, 1);                //屏幕刷新
    mtmMain.Register(Button_Update, 10);                //按键事件监控
    mtmMain.Register(Power_AutoShutdownUpdate, 100);    //自动关机监控
    mtmMain.Register(CPU_UsageUpdate, 1000);            //CPU占用率监控
}

/**
  * @brief  系统主循环
  * @param  无
  * @retval 无
  */
static void loop()
{
    mtmMain.Running(millis());
}

/**
  * @brief  Main Function
  * @param  None
  * @retval None
  */
int main(void)
{
    NVIC_SetPriorityGrouping(NVIC_PriorityGroup_2);
    Delay_Init();
    setup();
    for(;;)loop();
}

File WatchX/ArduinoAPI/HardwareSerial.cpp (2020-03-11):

/*
 * MIT License
 * Copyright (c) 2019 _VIFEXTech
 * 
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
 * THE SOFTWARE IS PROVIDED "AS IS", WITHOUT WARRANTY OF ANY KIND, EXPRESS OR
 * IMPLIED, INCLUDING BUT NOT LIMITED TO THE WARRANTIES OF MERCHANTABILITY,
 * FITNESS FOR A PARTICULAR PURPOSE AND NONINFRINGEMENT. IN NO EVENT SHALL THE
 * AUTHORS OR COPYRIGHT HOLDERS BE LIABLE FOR ANY CLAIM, DAMAGES OR OTHER
 * LIABILITY, WHETHER IN AN ACTION OF CONTRACT, TORT OR OTHERWISE, ARISING FROM,
 * OUT OF OR IN CONNECTION WITH THE SOFTWARE OR THE USE OR OTHER DEALINGS IN THE
 * SOFTWARE.
 */
#include "HardwareSerial.h"

/**
  * @brief  串口对象构造函数
  * @param  串口外设地址
  * @retval 无
  */
HardwareSerial::HardwareSerial(USART_TypeDef *_USARTx)
{
    this->USARTx = _USARTx;
    USART_Function = 0;
    _rx_buffer_head = _rx_buffer_tail = 0;
}

/**
  * @brief  串口中断入口
  * @param  无
  * @retval 无
  */
void HardwareSerial::IRQHandler()
{
    if(USART_GetITStatus(USARTx, USART_IT_RXNE) != RESET)
    {
        uint8_t c = USART_ReceiveData(USARTx);
        uint16_t i = (uint16_t)(_rx_buffer_head + 1) % SERIAL_RX_BUFFER_SIZE;
        if (i != _rx_buffer_tail)
        {
            _rx_buffer[_rx_buffer_head] = c;
            _rx_buffer_head = i;
        }

        if(USART_Function)
        {
            USART_Function();
        }

        USART_ClearITPendingBit(USARTx, USART_IT_RXNE);
    }
}

/**
  * @brief  串口初始化
  * @param  BaudRate: 波特率
  * @retval 无
  */
void HardwareSerial::begin(uint32_t BaudRate)
{
    begin(BaudRate, SERIAL_Config_Default);
}

/**
  * @brief  串口初始化
  * @param  BaudRate: 波特率
  * @param  Config: 配置参数
  * @retval 无
  */
void HardwareSerial::begin(uint32_t BaudRate, SERIAL_Config Config)
{
    begin(BaudRate, Config, USART_PreemptionPriority_Default, USART_SubPriority_Default);
}

/**
  * @brief  串口初始化
  * @param  BaudRate: 波特率
  * @param  Config: 配置参数
  * @param  PreemptionPriority: 抢占优先级
  * @param  SubPriority: 从优先级
  * @retval 无
  */
void HardwareSerial::begin(uint32_t BaudRate, SERIAL_Config Config, uint8_t PreemptionPriority, uint8_t SubPriority)
{
    GPIO_InitTypeDef GPIO_InitStructure;
    USART_InitTypeDef USART_InitStructure;
    NVIC_InitTypeDef NVIC_InitStructure;
    uint16_t Tx_Pin, Rx_Pin;
    uint16_t ItChannel;
    uint32_t RCC_AHB1Periph_GPIOx;
    GPIO_TypeDef *GPIOx;
    uint8_t GPIO_AF_USARTx;

    if(USARTx == USART1)
    {
        Tx_Pin = GPIO_Pin_9;
        Rx_Pin = GPIO_Pin_10;
        GPIOx = GPIOA;
        GPIO_AF_USARTx = GPIO_AF_USART1;
        RCC_AHB1Periph_GPIOx = RCC_AHB1Periph_GPIOA;
        RCC_APB2PeriphClockCmd(RCC_APB2Periph_USART1, ENABLE);
        ItChannel = USART1_IRQn;
    }
    else if(USARTx == USART2)
    {
        Tx_Pin = GPIO_Pin_2;
        Rx_Pin = GPIO_Pin_3;
        GPIOx = GPIOA;
        GPIO_AF_USARTx = GPIO_AF_USART2;
        RCC_AHB1Periph_GPIOx = RCC_AHB1Periph_GPIOA;
        RCC_APB1PeriphClockCmd(RCC_APB1Periph_USART2, ENABLE);
        ItChannel = USART2_IRQn;
    }
    else if(USARTx == USART3)
    {
        Tx_Pin = GPIO_Pin_10;
        Rx_Pin = GPIO_Pin_11;
        GPIOx = GPIOB;
        GPIO_AF_USARTx = GPIO_AF_USART3;
        RCC_AHB1Periph_GPIOx = RCC_AHB1Periph_GPIOB;
        RCC_APB1PeriphClockCmd(RCC_APB1Periph_USART3, ENABLE);
#if defined (STM32F40_41xxx) || defined (STM32F427_437xx) || defined (STM32F429_439xx)
        ItChannel = USART3_IRQn;
#endif
    }
    else return;

    RCC_AHB1PeriphClockCmd(RCC_AHB1Periph_GPIOx, ENABLE);

    GPIO_PinAFConfig(GPIOx, GPIO_GetPinSource(Tx_Pin), GPIO_AF_USARTx);
    GPIO_PinAFConfig(GPIOx, GPIO_GetPinSource(Rx_Pin), GPIO_AF_USARTx);

    GPIO_InitStructure.GPIO_Pin =  Tx_Pin | Rx_Pin;
    GPIO_InitStructure.GPIO_Speed = GPIO_Speed_100MHz;
    GPIO_InitStructure.GPIO_Mode = GPIO_Mode_AF;
    GPIO_InitStructure.GPIO_OType = GPIO_OType_PP;
    GPIO_InitStructure.GPIO_PuPd = GPIO_PuPd_UP;
    GPIO_Init(GPIOx, &GPIO_InitStructure);

    //Usart NVIC 配置
    NVIC_InitStructure.NVIC_IRQChannel = ItChannel;
    NVIC_InitStructure.NVIC_IRQChannelPreemptionPriority = PreemptionPriority ;//抢占优先级
    NVIC_InitStructure.NVIC_IRQChannelSubPriority = SubPriority;        //子优先级
    NVIC_InitStructure.NVIC_IRQChannelCmd = ENABLE;         //IRQ通道使能
    NVIC_Init(&NVIC_InitStructure); //根据指定的参数初始化VIC寄存器

    //USART 初始化设置
    USART_InitStructure.USART_BaudRate = BaudRate;//串口波特率
    USART_InitStructure.USART_WordLength = USART_GetWordLength(Config);//字长为8位数据格式
    USART_InitStructure.USART_StopBits = USART_GetParity(Config);//一个停止位
    USART_InitStructure.USART_Parity = USART_GetStopBits(Config);//无奇偶校验位
    USART_InitStructure.USART_HardwareFlowControl = USART_HardwareFlowControl_None;//无硬件数据流控制
    USART_InitStructure.USART_Mode = USART_Mode_Rx | USART_Mode_Tx; //收发模式

    USART_Init(USARTx, &USART_InitStructure); //初始化串口
    USART_ITConfig(USARTx, USART_IT_RXNE, ENABLE);//开启串口接受中断
    USART_Cmd(USARTx, ENABLE);                    //使能串口
}
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

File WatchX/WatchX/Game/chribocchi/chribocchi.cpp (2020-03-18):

#include "common.h"

#if ARDUBOY_LIB_VER != 10101
#error
#endif // It may work even if you use other version.

/*  Defines  */

enum MODE {
    LOGO_MODE = 0,
    TITLE_MODE,
    GAME_MODE
};

/*  Typedefs  */

typedef struct {
    void(*initFunc)(void);
    bool(*updateFunc)(void);
    void(*drawFunc)(void);
} MODULE_FUNCS;

/*  Global Variables  */

MyArduboy arduboy;

/*  Local Variables  */

static const MODULE_FUNCS moduleTable[] = {
    { initLogo,  updateLogo,  drawLogo },
    { initTitle, updateTitle, drawTitle },
    { initGame,  updateGame,  drawGame },
};

static MODE mode = LOGO_MODE;

/*  For Debugging  */

#ifdef DEBUG
bool    dbgPrintEnabled = true;
char    dbgRecvChar = '\0';
uint8_t dbgCaptureMode = 0;

static void dbgCheckSerialRecv(void) {
    int recv;
    while ((recv = Serial.read()) != -1) {
        switch (recv) {
        case 'd':
            dbgPrintEnabled = !dbgPrintEnabled;
            Serial.print("Debug output ");
            Serial.println(dbgPrintEnabled ? "ON" : "OFF");
            break;
        case 'c':
            dbgCaptureMode = 1;
            break;
        case 'C':
            dbgCaptureMode = 2;
            break;
        }
        if (recv >= ' ' && recv <= '~') dbgRecvChar = recv;
    }
}

static void dbgScreenCapture() {
    if (dbgCaptureMode) {
        Serial.write((const uint8_t *)arduboy.getBuffer(), WIDTH * HEIGHT / 8);
        if (dbgCaptureMode == 1) dbgCaptureMode = 0;
    }
}
#endif

/*---------------------------------------------------------------------------*/

static void setup()
{
#ifdef DEBUG
    Serial.begin(115200);
#endif
    arduboy.beginNoLogo();
    arduboy.setFrameRate(60);
    moduleTable[LOGO_MODE].initFunc();
}

static void loop()
{
#ifdef DEBUG
    dbgCheckSerialRecv();
#endif
    if (!(arduboy.nextFrame())) return;
    bool isDone = moduleTable[mode].updateFunc();
    moduleTable[mode].drawFunc();
#ifdef DEBUG
    dbgScreenCapture();
    dbgRecvChar = '\0';
#endif
    arduboy.display();
    if (isDone) {
        mode = (mode == TITLE_MODE) ? GAME_MODE : TITLE_MODE;
        moduleTable[mode].initFunc();
        dprint("mode=");
        dprintln(mode);
    }
}

static void exit()
{
    
}

#include "Game/GamePrivate.h"

void GameRegister_chrbocchi(uint8_t gameID)
{
    GamePage.PageRegister(gameID, setup, loop, exit, NULL);
}

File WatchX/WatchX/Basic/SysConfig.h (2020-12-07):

#ifndef __SYSCONFIG_H
#define __SYSCONFIG_H

#define WX_NAME             "WatchX"     //手表名称
#define WX_HARDWARE_VERSION "v2.0"       //硬件版本
#define WX_SOFTWARE_VERSION "v1.0"       //软件版本

/*屏幕*/
#define TFT_CS_Pin  PA4     //片选
#define TFT_DC_Pin  PA8     //数据/命令选择
#define TFT_RST_Pin PA1     //复位
#define TFT_BLK_Pin PA10    //背光

/*指示灯*/
#define LED_Pin     PC13

/*电源控制(ONLY Watch Max)*/
#define POWER_ON_Pin PA3    //电源保持
#define POWER_EN_Pin PA2    //电源使能

/*按键*/
#define KEY_UP_Pin   PB0    //上键
#define KEY_OK_Pin   PB1    //选择键
#define KEY_DOWN_Pin PB2    //下键

/*电池检测*/
#define BAT_DET_Pin PA6     //电压检测
#define BAT_CHG_Pin PA15    //充电检测

/*运动传感器*/
#define IMU_SCL_Pin PB6     //I2C时钟
#define IMU_SDA_Pin PB7     //I2C数据
#define IMU_INT_Pin PB5     //中断脚

/*气压计*/
#define BMP_SCL_Pin PB8     //I2C时钟
#define BMP_SDA_Pin PB9     //I2C数据

/*秒表功能使用的定时器*/
#define STOPWATCH_TIM TIM2

#endif

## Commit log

2020-03-11 首次更新
    ## [v0.2] - 2020-03-11
    * 1.主表盘界面完成
    * 2.设置界面完成
    * 3.时间设置界面完成
2020-03-12 更新 v0.3
    ## [v0.3] - 2020-03-12
    * 1.秒表完成
    * 2.海拔表完成
    * 3.About完成
    * 4.所有功能基本完工
2020-03-14 添加图片
2020-03-18 更新 v0.5
    ## [v0.5] - 2020-03-18
    * 1.添加低功耗模式
    * 2.添加Arduboy Game System
    * 3.添加游戏 "CHRI-BOCCHI CAT"
2020-03-23 更新 v0.6
    ## [v0.6] - 2020-03-23
    * 1.海拔显示添加自动量程
    * 2.添加MillisTaskManager，可统计CPU占用率
    * 3.添加时间上下滑动特效
2020-05-06 更新 v0.7
    ## [v0.7] - 2020-05-03
    * 1.屏幕使用DMA发送，配合lvgl乒乓缓冲，画面无撕裂
    * 2.Brightness更改为Backlight
2020-06-06 添加硬件设计图
    [WatchX.PcbDoc, WatchX.PrjPcb, WatchX.SchDoc]
2020-06-27 更新 v0.8
2020-07-08 更新PCB改进版
    感谢“日天电子工作室”提供的改进版PCB
    [WatchX.PcbDoc, WatchX.PrjPcb, WatchX.SchDoc]
2020-07-30 更新 v0.9
    ## [v0.9] - 2020-07-30
    * 1.更新MillisTaskManager库，无需手动指定ID
    * 2.TFT_BLK_Pin 更名为 TFT_BLK_Pin
    * 3.添加部分注释
    * 4.Home更名为DiolPlate(表盘)页面，Settings更名为MainMenu页面
    * 5.更新PageManager v1.4
    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
2020-12-07 更新 v1.0
    ## [v1.0] - 2020-12-07
    * 1.POWER初始化整合
    * 2.修改默认的动画曲线，更强的非线性效果，lv_anim_path_ease_in_out -> lv_anim_path_ease_out
    * 3.修正错误的单词拼写，xxx_Creat -> xxx_Create， Fouce -> Focus
    * 4.加大lv_disp_buf，使用两个半屏buffer，提升刷新率
    * 5.去除FileGroup.h
    * 6.更新海拔显示的tick自适应方法
    [BSP_Button.cpp, BSP_Power.cpp, Page_Game.cpp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]
